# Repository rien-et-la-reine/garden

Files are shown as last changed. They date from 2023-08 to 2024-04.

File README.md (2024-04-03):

# garden
a split 56 key columnar stagger keyboard with a tentable thumb cluster [WIP]

ZMK support using nice!nano v2: https://github.com/rien-et-la-reine/garden-path

*note: do NOT disconnect trrs connectors while power on, the way they are used here won't short VCC to ground or anything, but will short some columns/rows with each other which could be potentially damaging

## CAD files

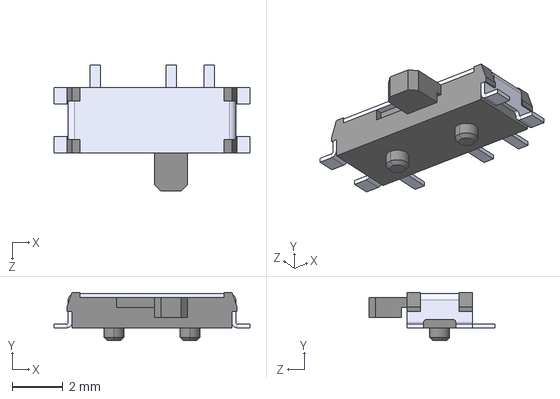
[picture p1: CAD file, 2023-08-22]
PCM12SMTR/PCM12SMTR.step
7.72 x 1.91 x 4.98 mm

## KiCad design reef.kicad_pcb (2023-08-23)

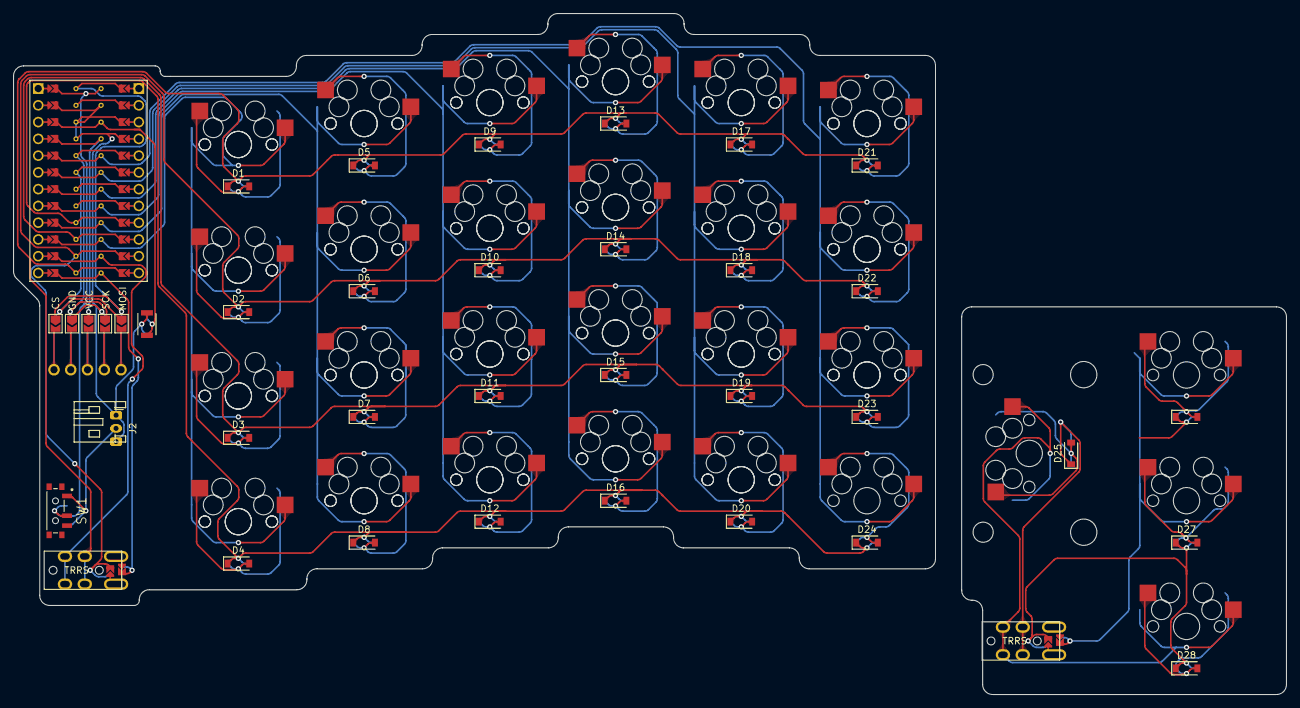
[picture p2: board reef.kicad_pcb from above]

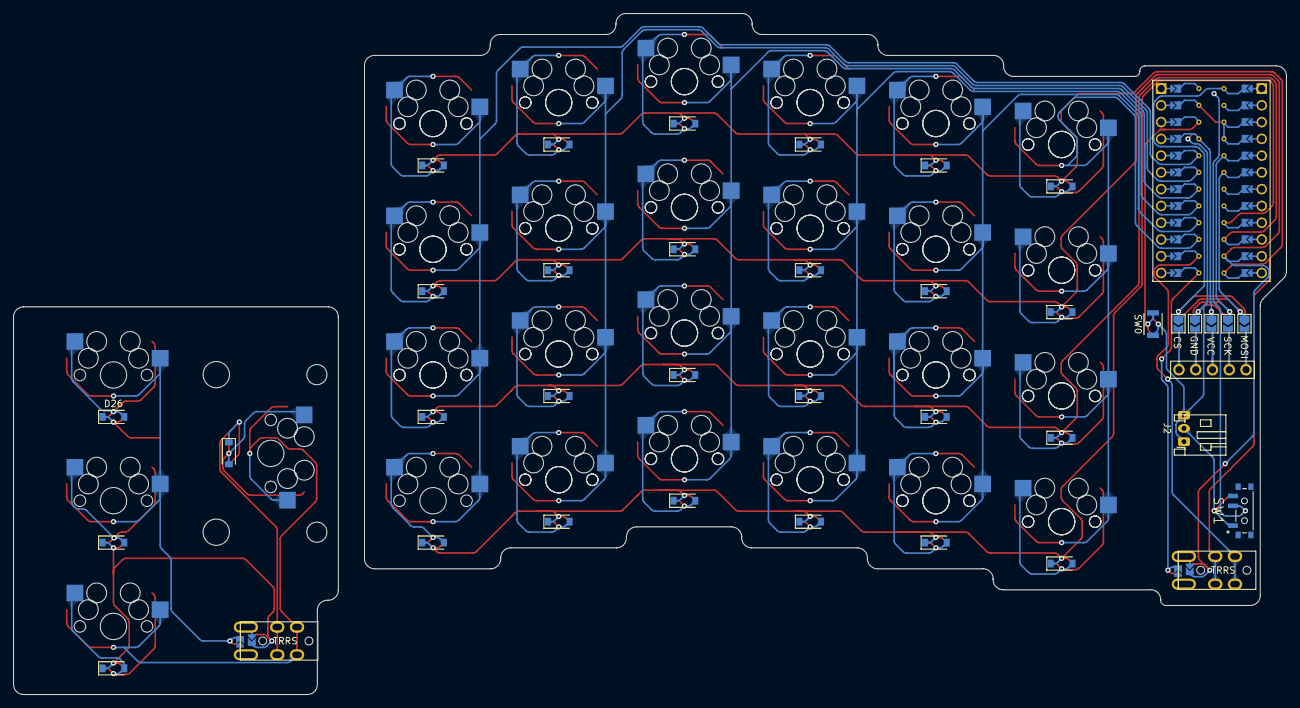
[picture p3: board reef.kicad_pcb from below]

Board: 2 copper layers, 139.7 x 89.7 mm, 87 parts (29 on the bottom side), 57 nets.

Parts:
D1, D2, D3, D4, D5, D6, D7, D8, D9, D10, D11, D12, D13, D14, D15, D16, D17, D18, D19, D20, D21, D22, D23, D24, D25, D26, D27, D28: D_Small; D_SOD-123_reversible
Display1: nice!view; nice_view_adapted
J1: nice!view sockets; nice_view_adapted
J2: battery connector; JST_PH_S2B-PH-K_1x02_P2.00mm_Horizontal
MX1, MX1#2, MX2, MX2#2, MX3, MX3#2, MX4, MX4#2, MX5, MX5#2, MX6, MX6#2, MX7, MX7#2, MX8, MX8#2, MX9, MX9#2, MX10, MX10#2, MX11, MX11#2, MX12, MX12#2, MX13, MX13#2, MX14, MX14#2, MX15, MX15#2, MX16, MX16#2, MX17, MX17#2, MX18, MX18#2, MX19, MX19#2, MX20, MX20#2, MX21, MX21#2, MX22, MX22#2, MX23, MX23#2, MX24: MX-NoLED; MXOnly-1U-Hotswap
MX25: MX-NoLED; MXOnly-2.25U-Hotswap
MX26, MX27, MX28: MX-NoLED; MXOnly-1.5U-Hotswap
SW0: B3U-1000P[]; SW_B3U-1000P_OMR
SW1: PCM12SMTR; SW_PCM12SMTR
U1: nice_nano; ProMicro
U2, U3: TRRS; PJ-320A

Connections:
unnamed: D1.2 (A), MX1.2 (ROW), MX1#2.2 (ROW)
unnamed: D2.2 (A), MX2.2 (ROW), MX2#2.2 (ROW)
unnamed: D3.2 (A), MX3.2 (ROW), MX3#2.2 (ROW)
unnamed: D4.2 (A), MX4.2 (ROW), MX4#2.2 (ROW)
unnamed: D5.2 (A), MX5.2 (ROW), MX5#2.2 (ROW)
unnamed: D6.2 (A), MX6.2 (ROW), MX6#2.2 (ROW)
unnamed: D7.2 (A), MX7.2 (ROW), MX7#2.2 (ROW)
unnamed: D8.2 (A), MX8.2 (ROW), MX8#2.2 (ROW)
unnamed: D9.2 (A), MX9.2 (ROW), MX9#2.2 (ROW)
unnamed: D10.2 (A), MX10.2 (ROW), MX10#2.2 (ROW)
unnamed: D11.2 (A), MX11.2 (ROW), MX11#2.2 (ROW)
unnamed: D12.2 (A), MX12.2 (ROW), MX12#2.2 (ROW)
unnamed: D13.2 (A), MX13.2 (ROW), MX13#2.2 (ROW)
unnamed: D14.2 (A), MX14.2 (ROW), MX14#2.2 (ROW)
unnamed: D15.2 (A), MX15.2 (ROW), MX15#2.2 (ROW)
unnamed: D16.2 (A), MX16.2 (ROW), MX16#2.2 (ROW)
unnamed: D17.2 (A), MX17.2 (ROW), MX17#2.2 (ROW)
unnamed: D18.2 (A), MX18.2 (ROW), MX18#2.2 (ROW)
unnamed: D19.2 (A), MX19.2 (ROW), MX19#2.2 (ROW)
unnamed: D20.2 (A), MX20.2 (ROW), MX20#2.2 (ROW)
unnamed: D21.2 (A), MX21.2 (ROW), MX21#2.2 (ROW)
unnamed: D22.2 (A), MX22.2 (ROW), MX22#2.2 (ROW)
unnamed: D23.2 (A), MX23.2 (ROW), MX23#2.2 (ROW)
unnamed: D24.2 (A), MX24.2 (ROW)
unnamed: D25.2 (A), MX25.2 (ROW)
unnamed: D26.2 (A), MX26.2 (ROW)
unnamed: D27.2 (A), MX27.2 (ROW)
unnamed: D28.2 (A), MX28.2 (ROW)
bat+: SW1.2, U1.24 (BATIN/P0.04)
bat_sw+: J2.2, SW1.1
col_0: MX1.1 (COL), MX1#2.1 (COL), MX2.1 (COL), MX2#2.1 (COL), MX3.1 (COL), MX3#2.1 (COL), MX4.1 (COL), MX4#2.1 (COL), U1.15 (P1.11)
col_1: MX5.1 (COL), MX5#2.1 (COL), MX6.1 (COL), MX6#2.1 (COL), MX7.1 (COL), MX7#2.1 (COL), MX8.1 (COL), MX8#2.1 (COL), U1.16 (P1.13)
col_2: MX9.1 (COL), MX9#2.1 (COL), MX10.1 (COL), MX10#2.1 (COL), MX11.1 (COL), MX11#2.1 (COL), MX12.1 (COL), MX12#2.1 (COL), U1.17 (P1.15)
col_3: MX13.1 (COL), MX13#2.1 (COL), MX14.1 (COL), MX14#2.1 (COL), MX15.1 (COL), MX15#2.1 (COL), MX16.1 (COL), MX16#2.1 (COL), U1.18 (AIN0/P0.02)
col_4: MX17.1 (COL), MX17#2.1 (COL), MX18.1 (COL), MX18#2.1 (COL), MX19.1 (COL), MX19#2.1 (COL), MX20.1 (COL), MX20#2.1 (COL), U1.19 (AIN5/P0.29)
col_5: MX21.1 (COL), MX21#2.1 (COL), MX22.1 (COL), MX22#2.1 (COL), MX23.1 (COL), MX23#2.1 (COL), MX24.1 (COL), U1.20 (AIN7/P0.31)
col_6: U1.14 (NFC2/P0.10), U2.4 (RING2)
col_7: U1.13 (NFC1/P0.09), U2.1 (SLEEVE)
cs: J1.5, U1.1 (TX0/P0.06)
disp_1: Display1.1, J1.6, J1.10
disp_2: Display1.2, J1.7, J1.9
disp_3: Display1.3, J1.8
disp_4: Display1.4, J1.7, J1.9
disp_5: Display1.5, J1.6, J1.10
gnd: J1.4, J2.1, SW0.1, U1.3 (GND), U1.4 (GND), U1.23 (GND)
mosi: J1.1, U1.6 (P0.20)
row_0: D1.1 (K), D5.1 (K), D9.1 (K), D13.1 (K), D17.1 (K), D21.1 (K), U1.12 (P1.06), U2.3 (RING1)
row_1: D2.1 (K), D6.1 (K), D10.1 (K), D14.1 (K), D18.1 (K), D22.1 (K), U1.11 (P1.04), U2.2 (TIP)
row_2: D3.1 (K), D7.1 (K), D11.1 (K), D15.1 (K), D19.1 (K), D23.1 (K), U1.10 (P0.11)
row_3: D4.1 (K), D8.1 (K), D12.1 (K), D16.1 (K), D20.1 (K), D24.1 (K), U1.9 (P1.00)
rst: SW0.2, U1.22 (RST)
sck: J1.2, U1.5 (P0.17)
thc_6: MX25.1 (COL), MX28.1 (COL), U3.4 (RING2)
thc_7: MX26.1 (COL), MX27.1 (COL), U3.1 (SLEEVE)
thr_0: D25.1 (K), D26.1 (K), U3.3 (RING1)
thr_1: D27.1 (K), D28.1 (K), U3.2 (TIP)
vcc: J1.3, U1.21 (VCC)

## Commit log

2023-08-12 init KiCAD project
    created the KiCAD project
    [reef.kicad_pcb, reef.kicad_sch]
2023-08-12 init project libraries
    initialize symbol and footprint libraries into KiCAD project
2023-08-18 additional config
    [reef.kicad_sch]
2023-08-19 schematic complete
    finished schematic, assigned footprints for most components (except connectors)
    [reef.kicad_sch]
2023-08-20 update connectors
    update board and thumb cluster conectors (using SF7381-5PG-3ES 5 pin panel mount connector)
    [reef.kicad_sch]
2023-08-20 Connector Change
    switching to slightly smaller T4140012051-000 connector.
    [reef.kicad_sch]
2023-08-20 init PCB
    initialise PCB from schematic
    [reef.kicad_pcb]
2023-08-20 PCB Layout
    layout of keys, controller board, connectors + routed matrix columns
    [reef.kicad_pcb]
2023-08-20 PCB updates + importing keebio library
    [reef.kicad_pcb, reef.kicad_sch]
2023-08-21 Updated Layout
    modified layout to use trrs to connect with thumb cluster, added connector for battery, and footprint for nice!view display
    [reef.kicad_pcb, reef.kicad_sch]
2023-08-21 Flipside Linkage
    connected diode pads to their flipside counterparts, thumb cluster should now be fully routed, to be ground-planed later
    [reef.kicad_pcb]
2023-08-21 Thumb Cluster Routing
    thumb cluster routing should NOW be complete (rows were not connected up previously)
    [reef.kicad_pcb]
2023-08-21 Matrix Routing
    Routing for the switch matrix (including some things missed from the thumb cluster yet again) should now be complete
    [reef.kicad_pcb]
2023-08-21 Route Display
    Display connected to nice!nano. in order to keep pcb reversible, jumper wire will be soldered between the actual display pad footprint and the appropriate column of pads (J1)
    [reef.kicad_pcb, reef.kicad_sch]
2023-08-22 new submodule for reversible footprints
    [reef.kicad_pcb]
2023-08-22 Reversible via Jumper Pads
    using solder jumper pads to make component footprints reversible
    [reef.kicad_pcb, reef.kicad_sch]
2023-08-22 Display Routing
    Traces for display should no longer interfere with routing columns and rows to their respective pins in an aesthetically pleasing manner...hopefully
    [reef.kicad_pcb, reef.kicad_sch]
2023-08-22 Matrix Reroute
    rerouted some matrix traces to connect to vias instead of going through diode pads
    [reef.kicad_pcb]
2023-08-22 Remove Unused Library
    removing now unused library for m12 5 pin connector
2023-08-22 Routed Battery Connector
    routed traces for battery connector
    [reef.kicad_pcb, reef.kicad_sch]
2023-08-22 Reset and Power switches in progress
    [reef.kicad_pcb, reef.kicad_sch]
2023-08-22 Power and Reset switch symbols and footprints
    [PCM12SMTR.step]
2023-08-23 Power and Reset schematics
    added power and reset switches to schematic
    [reef.kicad_sch]
2023-08-23 Power and Reset footprints
    added footprints for power and reset switches to PCB
    [reef.kicad_pcb]
2023-08-23 Reset, Power, Battery
    routed reset switch, power switch, battery connector
    [reef.kicad_pcb]
2023-08-23 Ports and Switches
    rerouted reset switch, routed trrs connector. all switches and ports should now be routed
    [reef.kicad_pcb]
2023-08-23 Layout
    arranged everything in rough layout of final board
    [reef.kicad_pcb]
2023-08-23 Traces Routed
    all traces should now be fully routed
    [reef.kicad_pcb, reef.kicad_sch]
2023-08-23 Teardrops and Fillets
    [reef.kicad_pcb]
2023-08-23 Ground Fill
    added ground fill to front and back copper layers (to hopefully mitigate any potential interference that might occur)
2023-08-23 Ground Fillet
    filleted ground plane zones
2023-08-23 Zone Clearance
    increased zone minimum clearance to prevent overlap of ground fill with teardrops
2023-08-23 Teardrops and Edge Cuts
    migrated to KiCAD v7, added back teardrops and edgecuts
    [reef.kicad_pcb]
2023-08-23 Ground Fill and Mousebites
    attached thumb cluster to main board with mousebites, added back ground fill
2023-08-23 Ground Stitching
    stitching together ground pours with freestanding vias
2023-08-24 Rotated TRRS Port
    rotated the TRRS port on the main board to face the bottom (will make it easier to connect to the thumb cluster)
    [reef.kicad_sch]
2023-08-24 Mounting Holes
    added holes for M2 standoffs for mounting to a bottom plate. went a little overboard with the holes, revision 2 of this board will only keep the ones needed
2024-03-29 generated drill files
    [garden-B_Cu.gbr, garden-B_Mask.gbr, garden-B_Paste.gbr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]
2024-03-29 cleanup
    removing gerber and drill files
    [garden-B_Cu.gbr, garden-B_Mask.gbr, garden-B_Paste.gbr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]
